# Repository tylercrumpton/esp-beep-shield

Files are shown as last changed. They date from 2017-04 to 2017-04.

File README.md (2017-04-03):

# BEEP Shield
Passive piezo buzzer shield for the D1 Mini ESP8266 board.

pcb-frontpcb-back

## Overview
The **BEEP Shield** fits the Wemos D1 Mini ESP8266 development boards and contains a 5V "passive" piezo buzzer.
This allows you to make tones from 2KHz to 5KHz using a single IO pin.

## Operation
The **BEEP Shield** works well with the Arduino `tone()` function, and the pin mappings are as follows:

| Description | D1 Mini Pin |
|---|---|
| 5V Supply | 5V |
| Ground | GND |
| Buzzer Control | D6 |

All other pins are not used and are not connected.

[pcb-front]: https://cloud.githubusercontent.com/assets/1317406/24598057/14bfc128-180f-11e7-8c8c-d3699ac8b2c8.png
[pcb-back]: https://cloud.githubusercontent.com/assets/1317406/24598063/1cf48612-180f-11e7-97a8-c578592f99b6.png

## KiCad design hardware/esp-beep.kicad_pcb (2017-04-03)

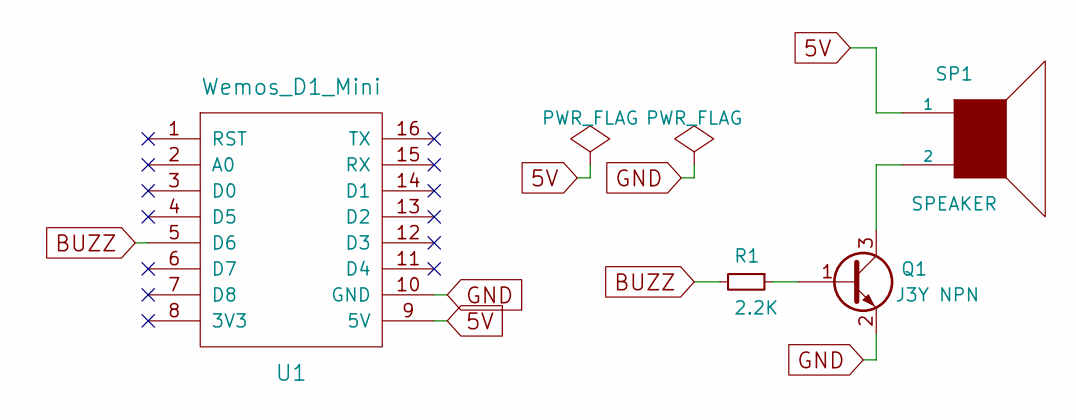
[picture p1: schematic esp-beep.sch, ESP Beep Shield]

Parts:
Q1: J3Y NPN; SOT-23_Handsoldering
R1: 2.2K; R_0805_HandSoldering
SP1: SPEAKER; 5V_buzzer
U1: Wemos_D1_Mini; D1_mini

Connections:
5V: SP1.1, U1.9 (5V)
BUZZ: R1.2, U1.5 (D6)
GND: Q1.2 (E), U1.10 (GND)
unnamed: Q1.1 (B), R1.1
unnamed: Q1.3 (C), SP1.2

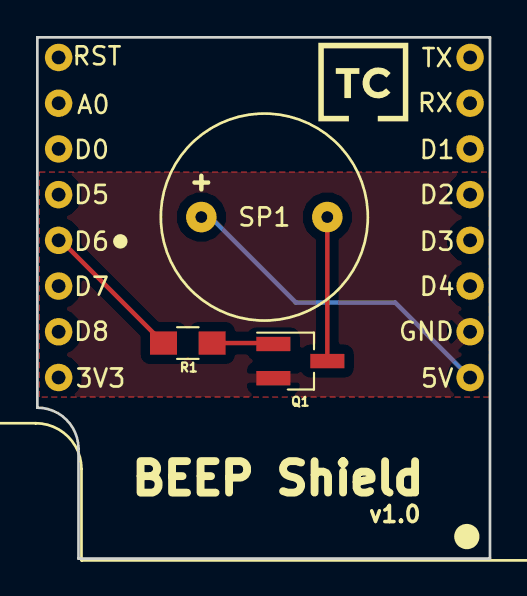
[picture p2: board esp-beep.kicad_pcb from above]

Board: 2 copper layers, 25.1 x 29.0 mm, 6 parts (1 on the bottom side), 5 nets.

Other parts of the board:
svg2mod, svg2mod#2: G***; tc_30mm

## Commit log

2017-03-30 Initial project setup.
    [esp-beep.kicad_pcb, esp-beep.sch]
2017-04-03 Update CrumpPrints to include 5V buzzer.
2017-04-03 Capture schematic layout.
    [esp-beep.sch]
2017-04-03 Add empty ProjectSpecific footprint repo.
2017-04-03 Assign footprints to schematic symbols.
    [esp-beep.sch]
2017-04-03 Add PCB layout.
    [esp-beep.kicad_pcb]
2017-04-03 Add plot settings to PCB.
    [esp-beep.kicad_pcb]

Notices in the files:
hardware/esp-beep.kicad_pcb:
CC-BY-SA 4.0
